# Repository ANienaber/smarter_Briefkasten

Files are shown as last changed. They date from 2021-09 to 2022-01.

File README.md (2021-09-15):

Der smarte Briefkasten, ermöglicht es Pakete von Personen zu empfangen, wenn man nicht anwesend ist. 
Wird von dem vorne liegenden RFID-Sensor ein autorisierter Tag erkannt, öffnen sich die Türen des Briefkasten. Legt man nun einen Gegenstand in den Briefkasten hinein, erkennt ein eingebauter Abstandssensor diesen und sendet durch die App Blynk eine Push Benachrichtung an das Handy des Nutzers. 
Geschlossen werden die Türen durch einen Knopfdruck.

Für den Zusammenbau werden MDF Holzbretterund Acrylglas, die mit einem Lasercutter geschnitten werden, ein 3D-Drucker. Hiermit werden die Modelle, die in dem Ordner Modellierung zu finden sind, gefertigt. Diese Modelle werden zusammengesteckt und geklebt
Zu dieser Hardware gehören, zwei ESP8266 D1 Mini Mikrocontroller, ein Taster, eine Tripler Base, ein Motorshield, zwei DC-Motoren, ein RFID-Sensor, und ein Abstandssensor.
Die beiden Dateien, die in dem Programmieren Ordner zu finden sind, müssen jeweils auf einen Mikrocontroller hochgeladen werden. 
Weitere Angaben zum Zusammenbau des Briefkasten können auf dem zugehörigen Blog gelesen werden. https://wp.uni-oldenburg.de/soft-skills-und-technische-kompetenz-wise20202021-sosepg-4/

Der Briefkasten wird wie folgt genutzt:
Bei erstmaliger Nutzung muss die Blynk App verbunden werden. Hierfür müssen im Programmcode die Wlan-Daten und der Authentifizierungstoken ergänzt werden. 
Außerdem sollte darauf geachtet werden, dass vor dem Start die Türen geschlossen sind. Ansonsten kann es sein, dass sich die Türen zu weit drehen. 
Die vorgesehene Bedienung des Briefkastens sieht wie folgt aus:

1. Den RFID Chip vor dem RFID Sensor halten, damit sich die Türen öffnen
2. Das Paket bzw. ein Gegenstand in den Briefkasten legen. Dann wird über die Blynk App eine Push Nachricht gesendet
3. Den Knopf betätigen, sodass sich die Türen wieder schließen
4. Mit dem RFID Chip die Türen wieder öffnen und das Paket entnehmen
5. Mit dem Knopf die Türen wieder schließen

Bekannte Probleme:
Türen lassen sich nicht mit dem RFID Chip öffnen:
Die Stromversorgung  muss neu eingeschaltet werden, bis die Türen wieder funktionieren. Bei erstmaliger Durchführung funktioniert es meist wieder.
Wenn der Briefkasten längere Zeit nicht genutzt wird, kann dieses Problem auftreten.

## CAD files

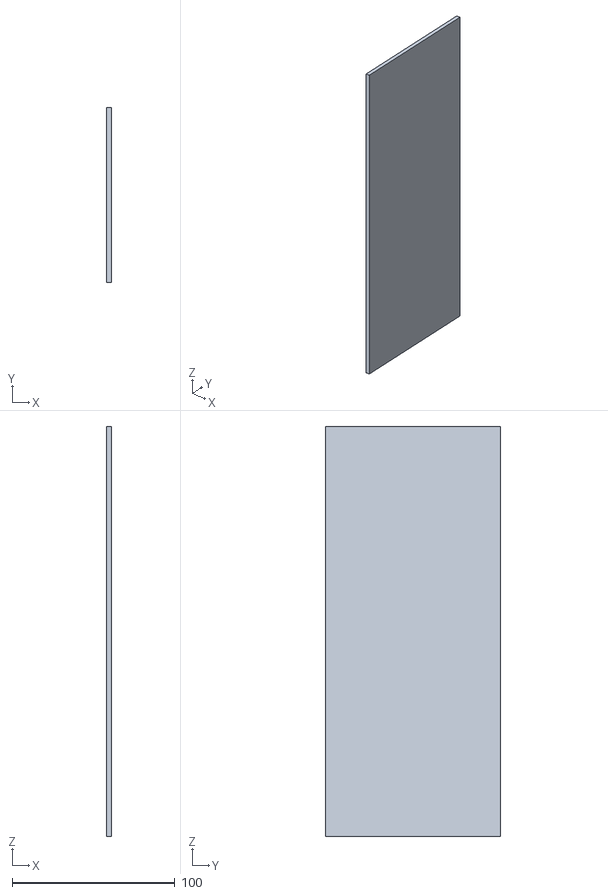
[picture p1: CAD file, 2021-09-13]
Modellierung/Tür.stl
3.00 x 107.5 x 252.0

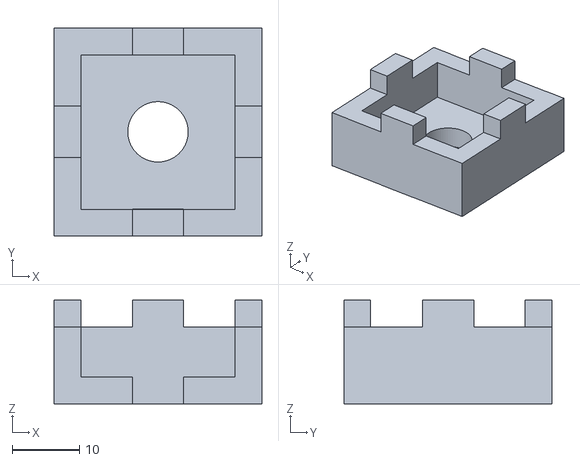
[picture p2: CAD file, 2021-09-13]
Modellierung/Kugellagerhalterung.stl
31.0 x 31.0 x 15.5

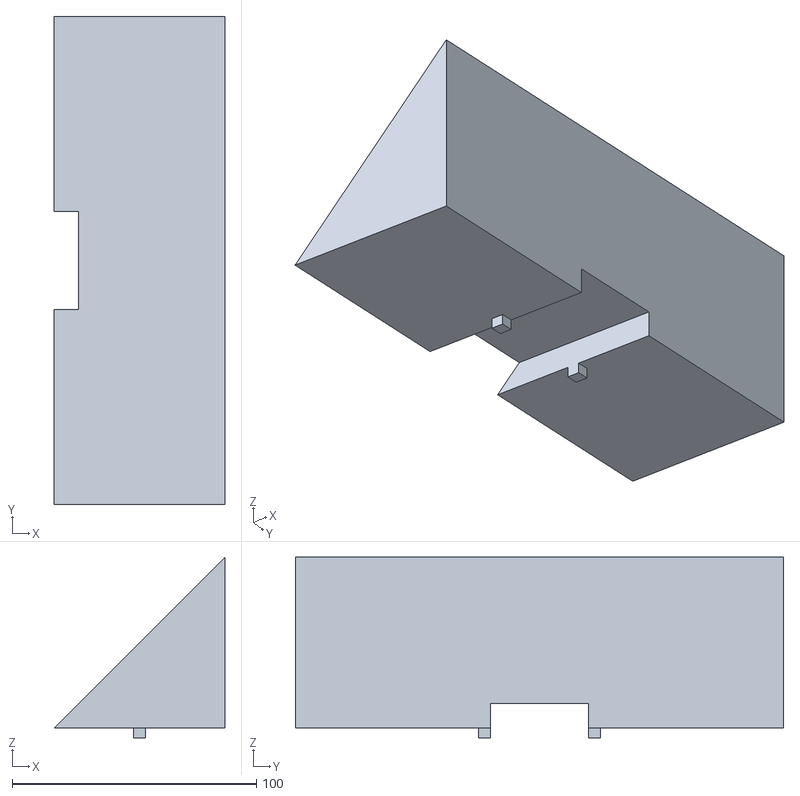
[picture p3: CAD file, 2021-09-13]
Modellierung/Schräge.stl
70.0 x 200.0 x 74.0

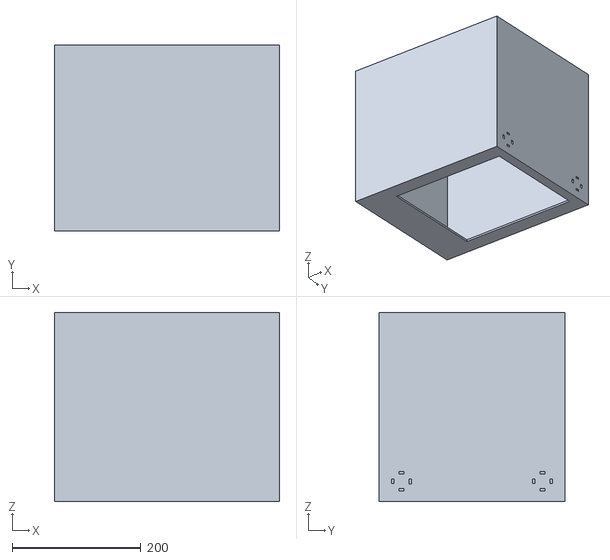
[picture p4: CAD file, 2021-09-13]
Modellierung/Oberkasten.stl
350.0 x 290.0 x 294.0

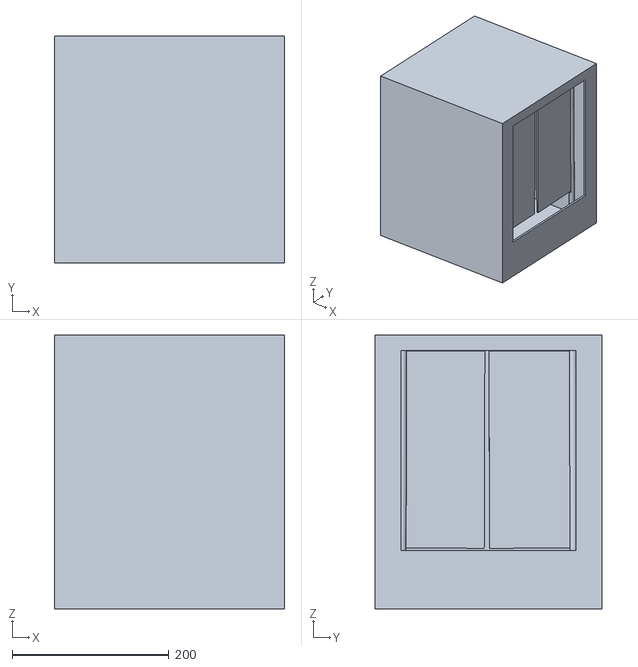
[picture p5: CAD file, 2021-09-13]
Modellierung/Gesamten_Oberkasten.stl
294.0 x 290.0 x 350.0

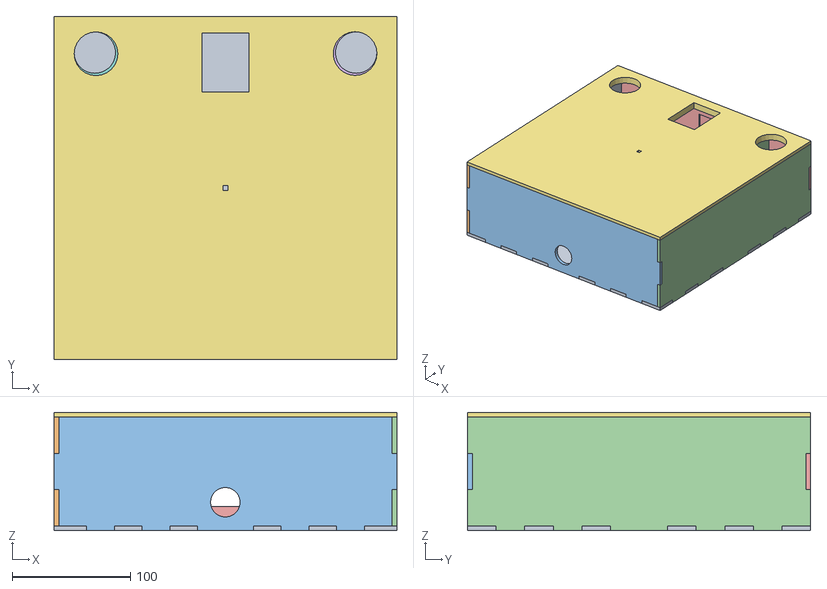
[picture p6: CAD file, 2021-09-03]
Modellierung/Unterbox.obj
290.0 x 290.1 x 100.0
Deckel

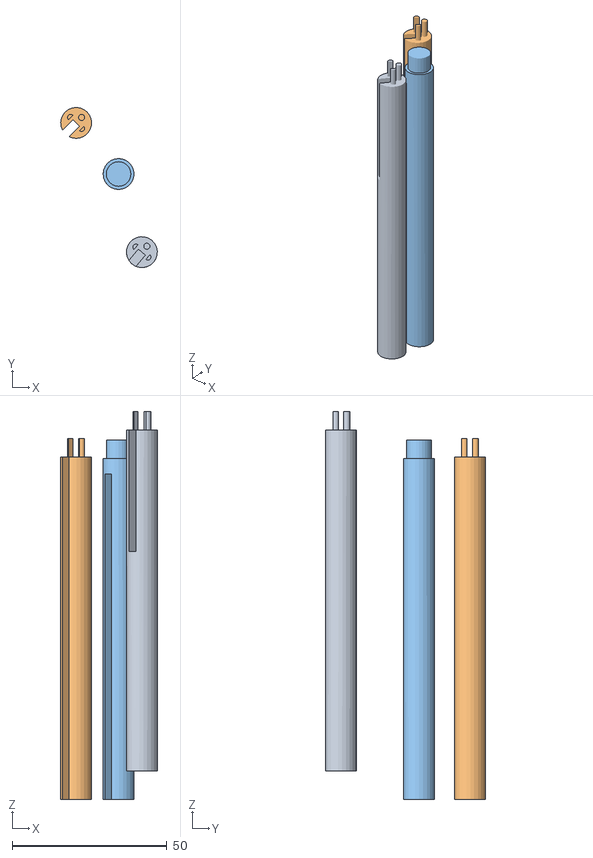
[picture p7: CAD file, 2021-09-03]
Modellierung/Saeule.obj
31.2 x 51.7 x 125.4
Säule unten
Säule mitte
Säule oben

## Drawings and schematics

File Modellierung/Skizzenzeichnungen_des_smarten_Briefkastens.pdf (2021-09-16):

9 | 10 | 11 | 12 | 13 | 14 | 15 | 16 | 17 | 18 | 19 | 20 | 21 | 22 | 23 | 24

290

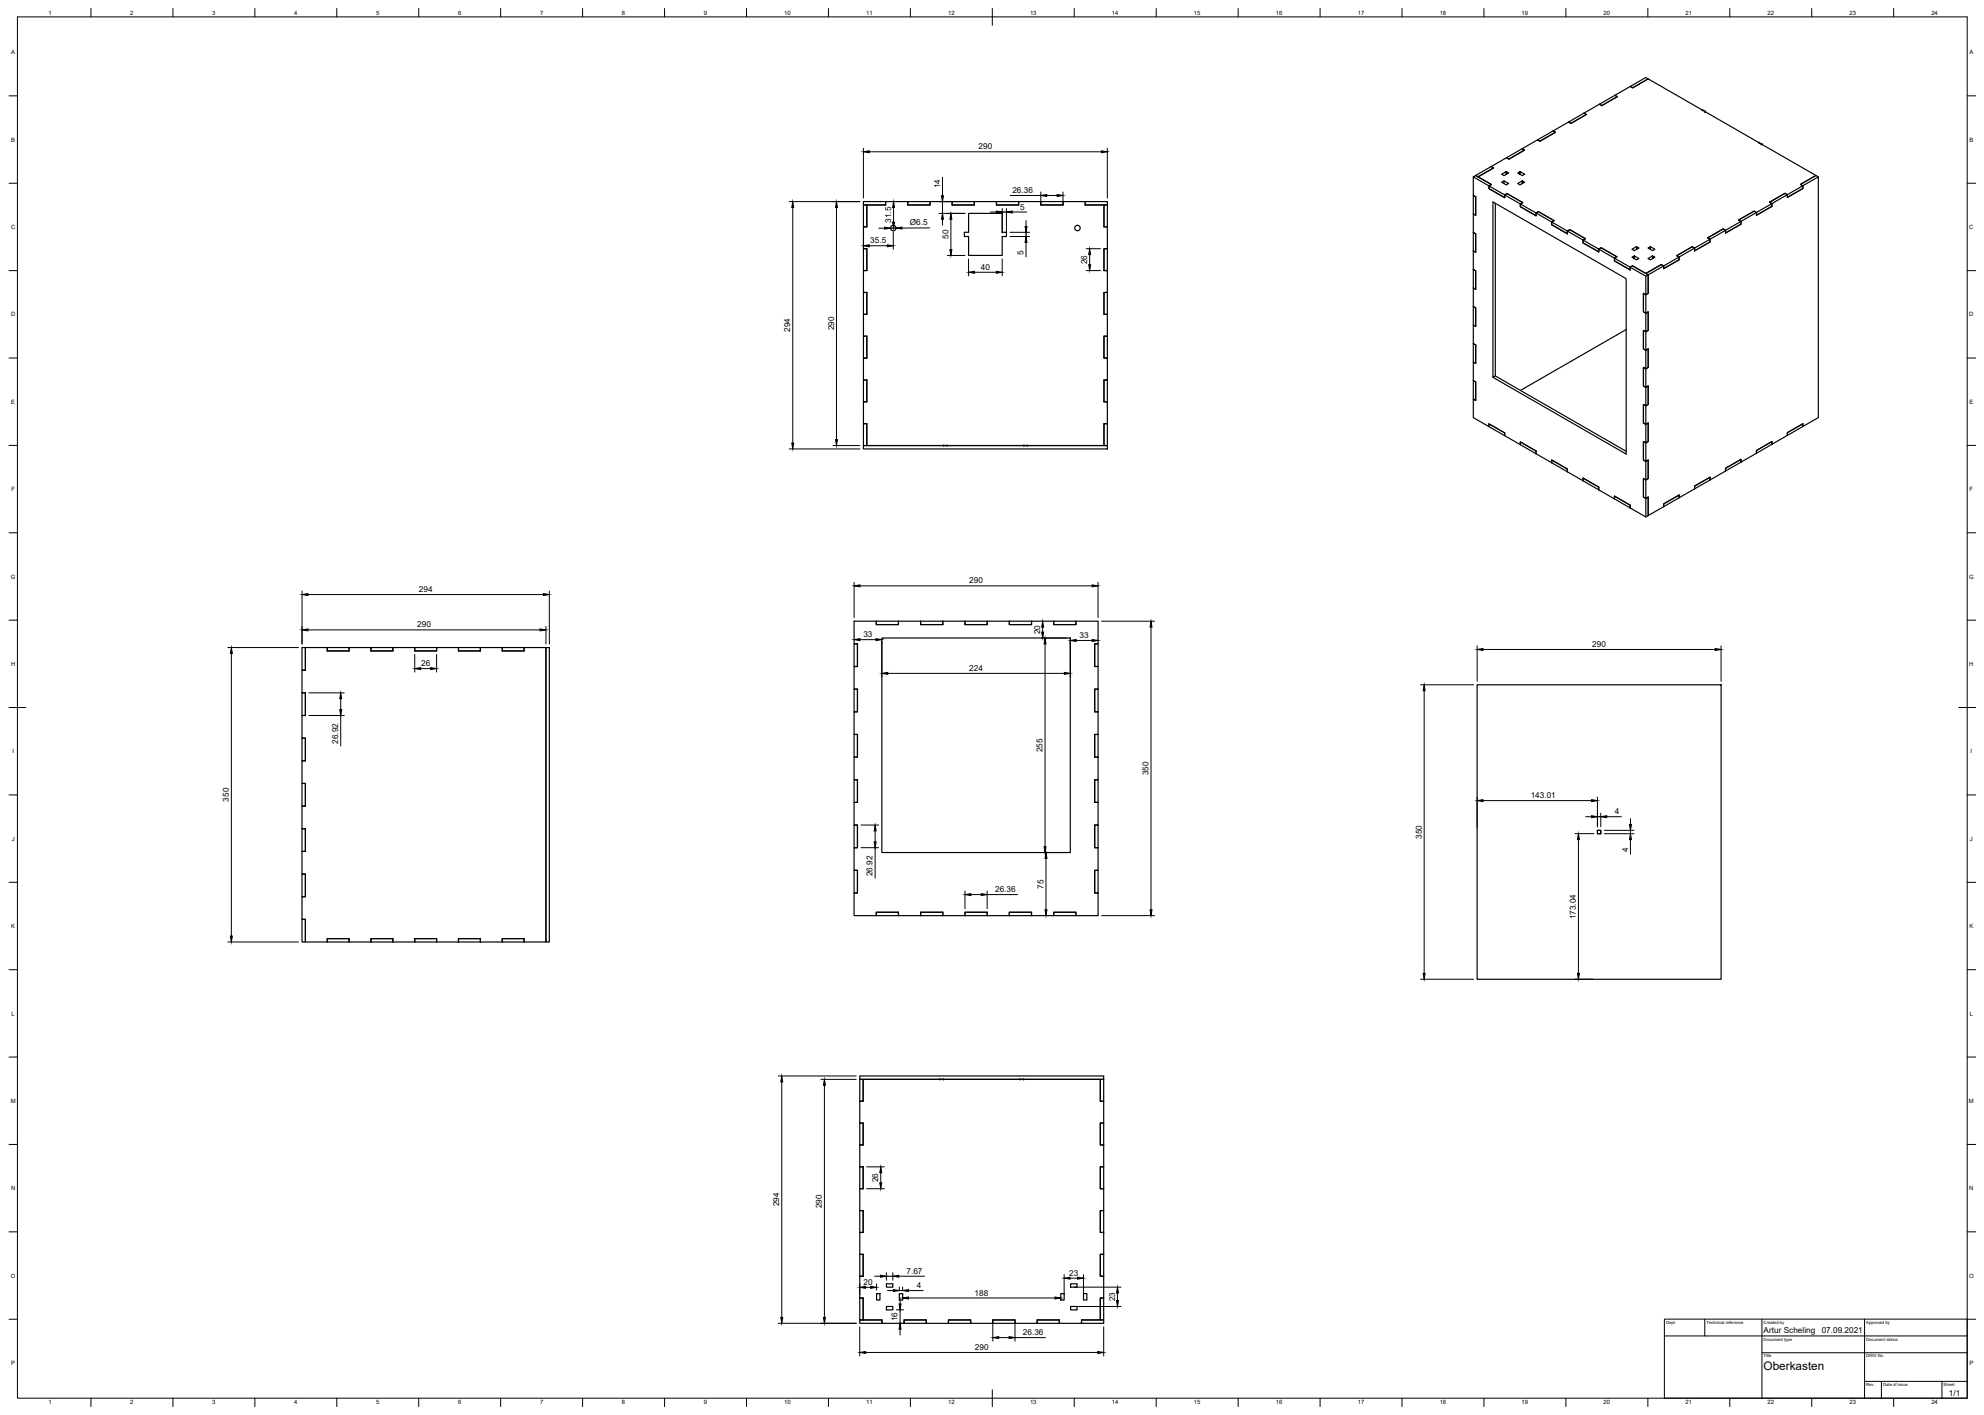
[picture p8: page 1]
BADCFEHGIKJMLONP; Dept.; Technical reference; Created by; Approved by; Artur Scheling

Document type | Document status

Title Oberkasten | DWG No.

Rev. | Date of issue | Sheet

1 | 2 | 3 | 4 | 5 | 6 | 7 | 8 | 9 | 10 | 11 | 12 | 13 | 14 | 15 | 16

B

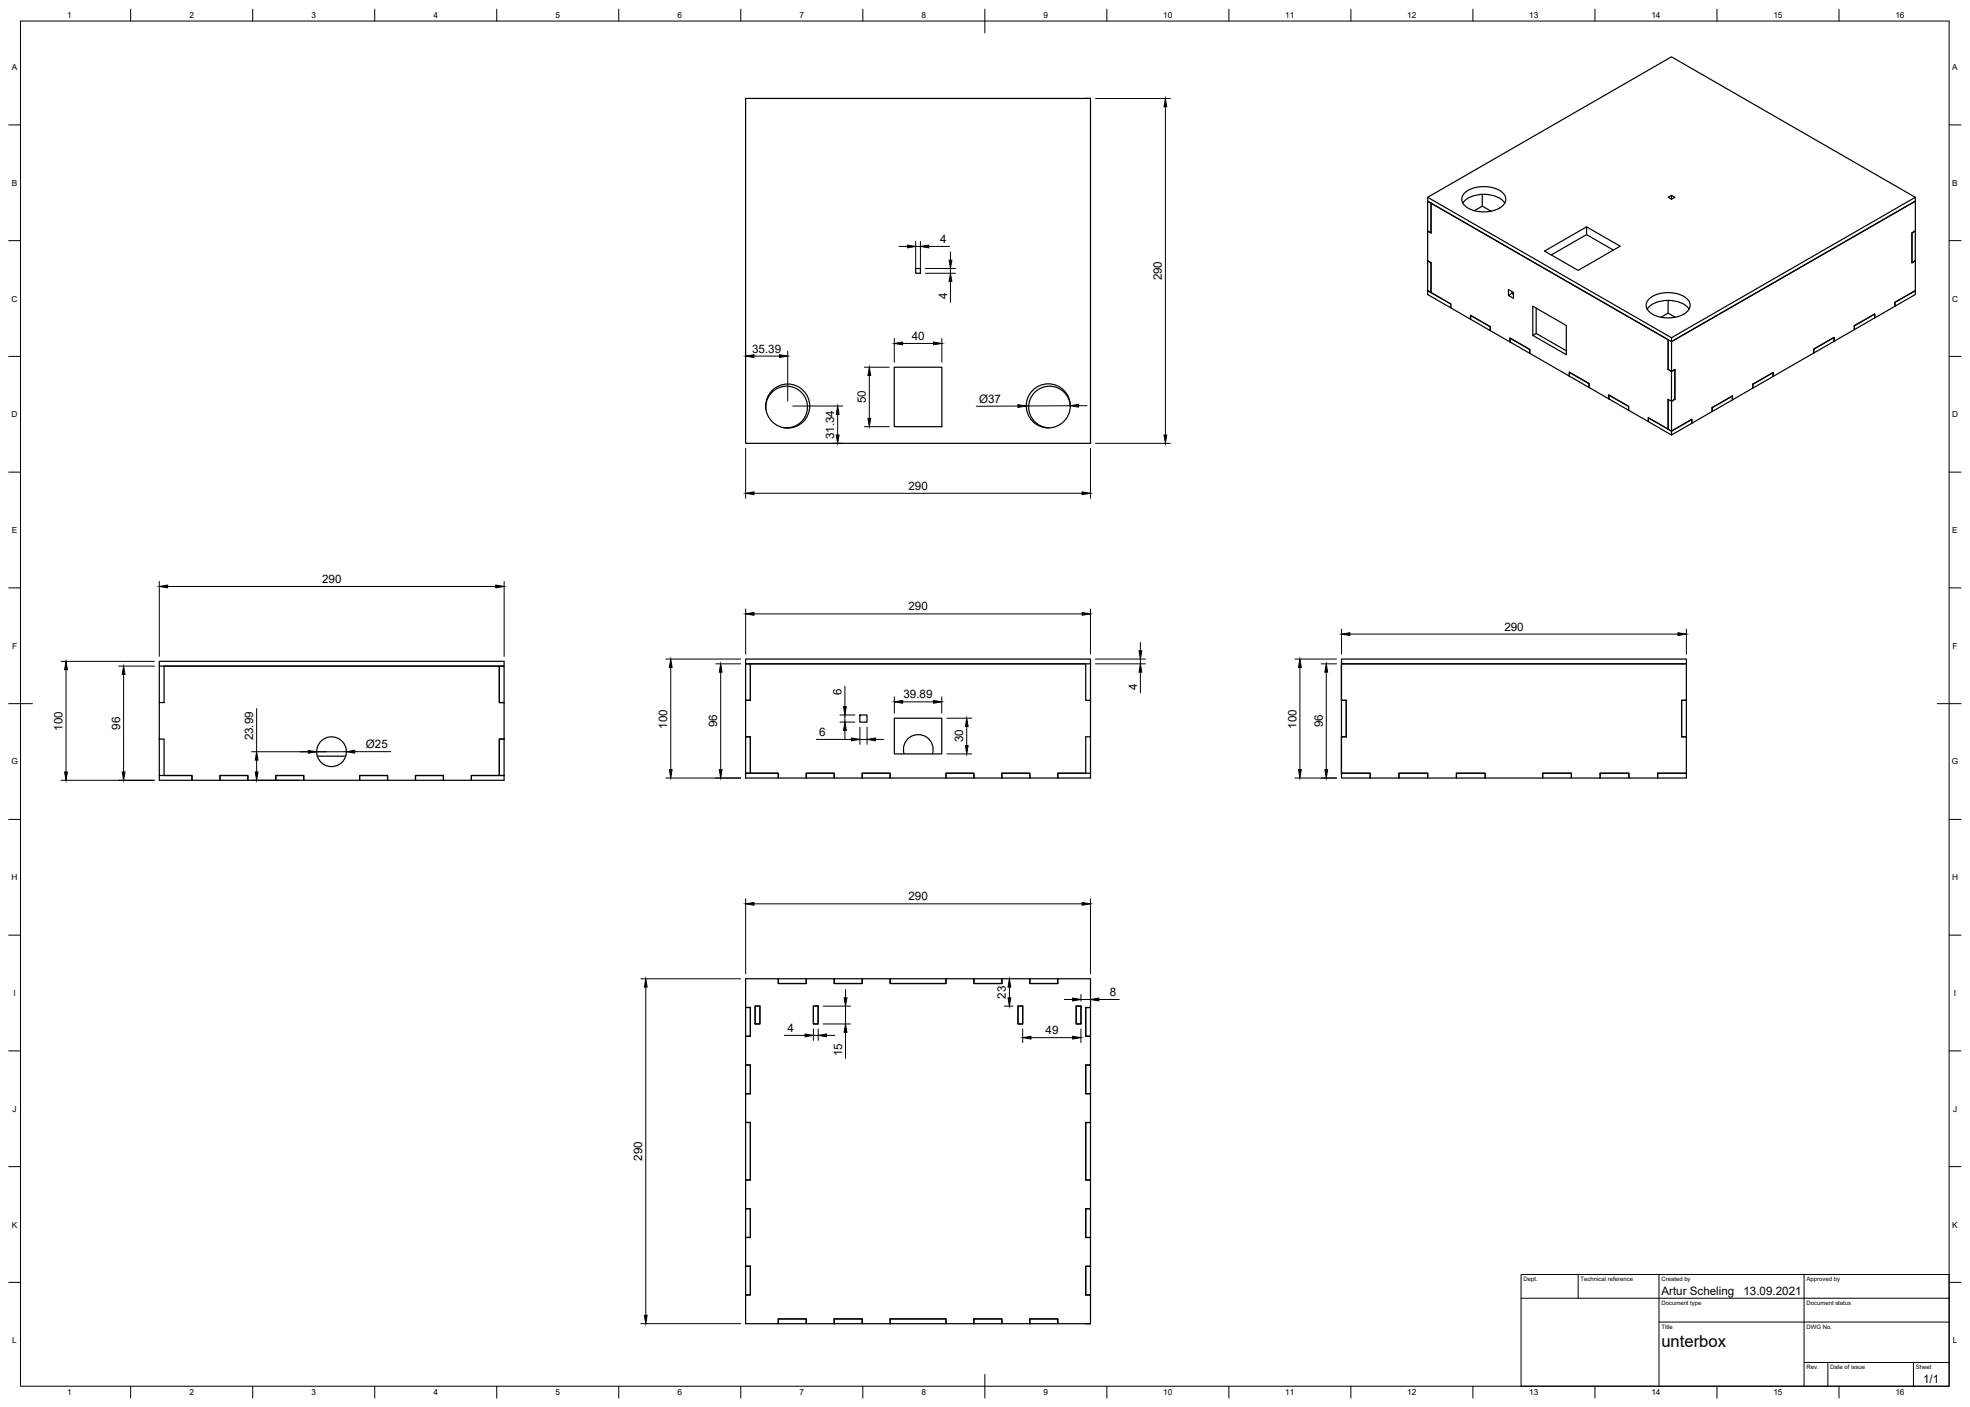
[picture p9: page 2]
Dept.; Technical reference; Created by; Approved by; Document type; Document status; unterbox; Artur Scheling

A

2 | 3 | 4 | 5 | 6 | 7 | 8

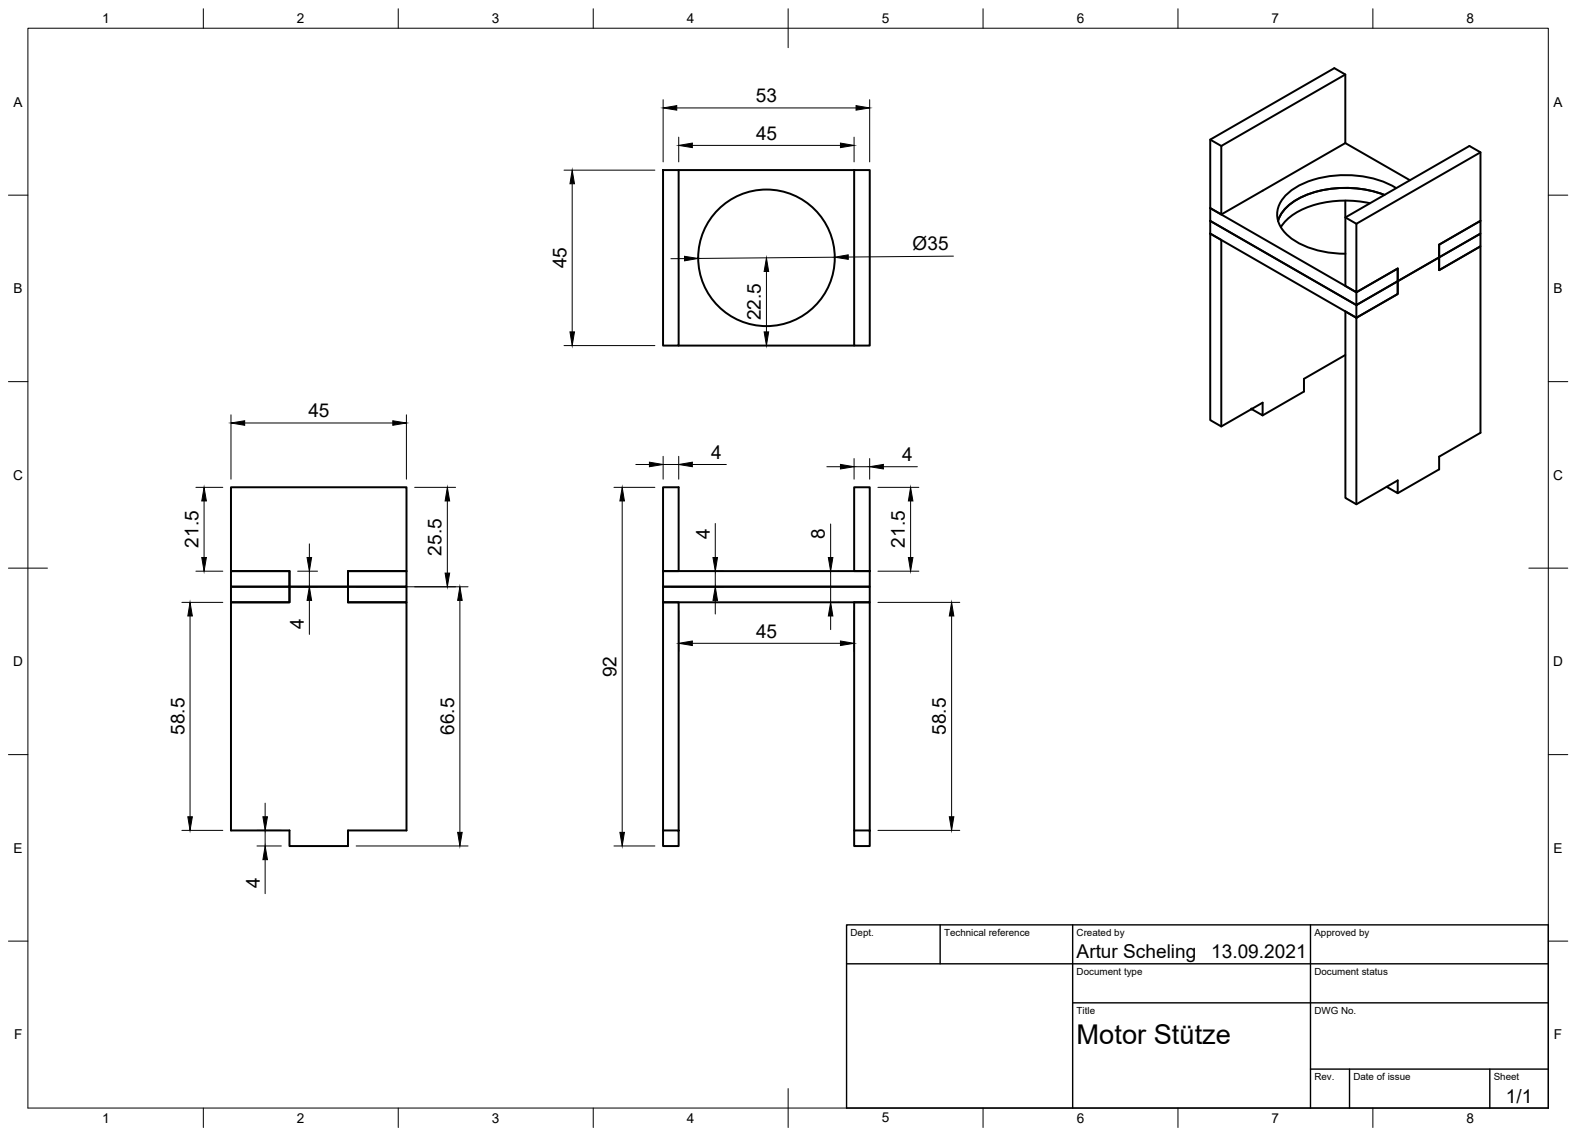
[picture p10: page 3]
Dept.; Technical reference; Created by; Approved by; Document type; Document status; Title; DWG No.; Motor Stütze; Artur Scheling

A

2 | 3 | 4 | 5 | 6 | 7 | 8

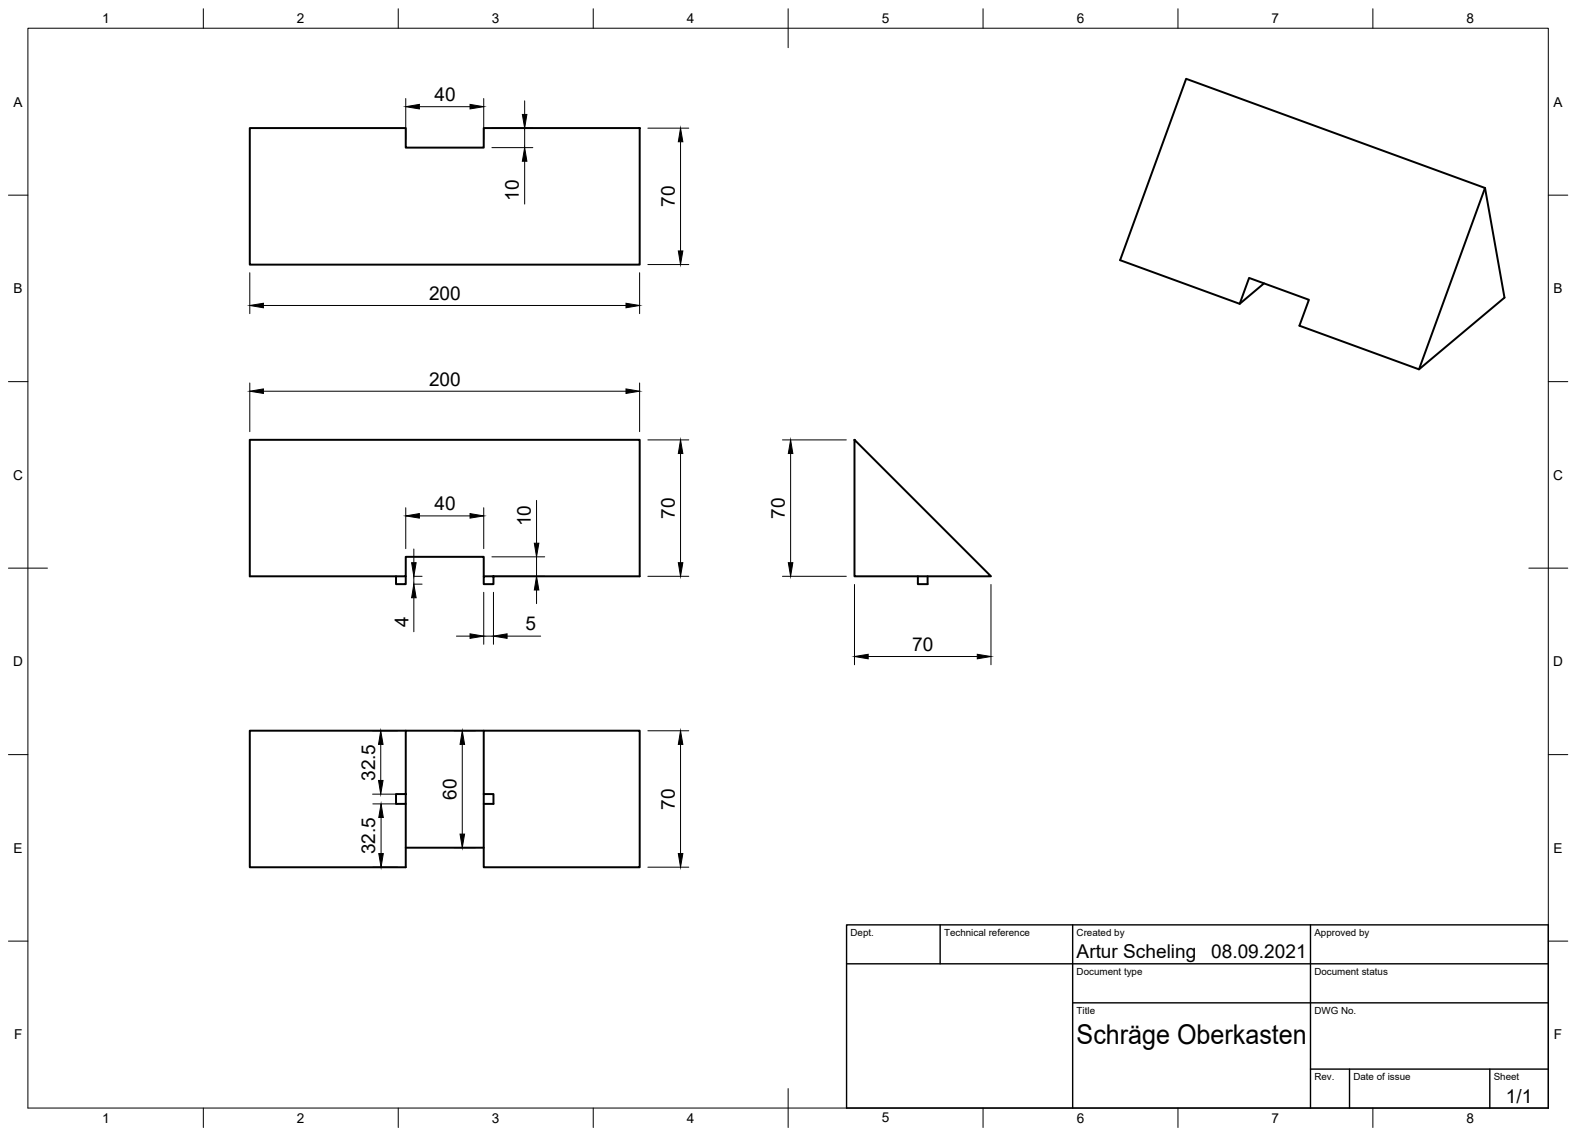
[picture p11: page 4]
Dept.; Technical reference; Created by; Approved by; Document type; Document status; Title; DWG No.; Schräge Oberkasten; Artur Scheling

1 | 2 | 3 | 4 | 5 | 6 | 7 | 8 | 9 | 10 | 11 | 12

B

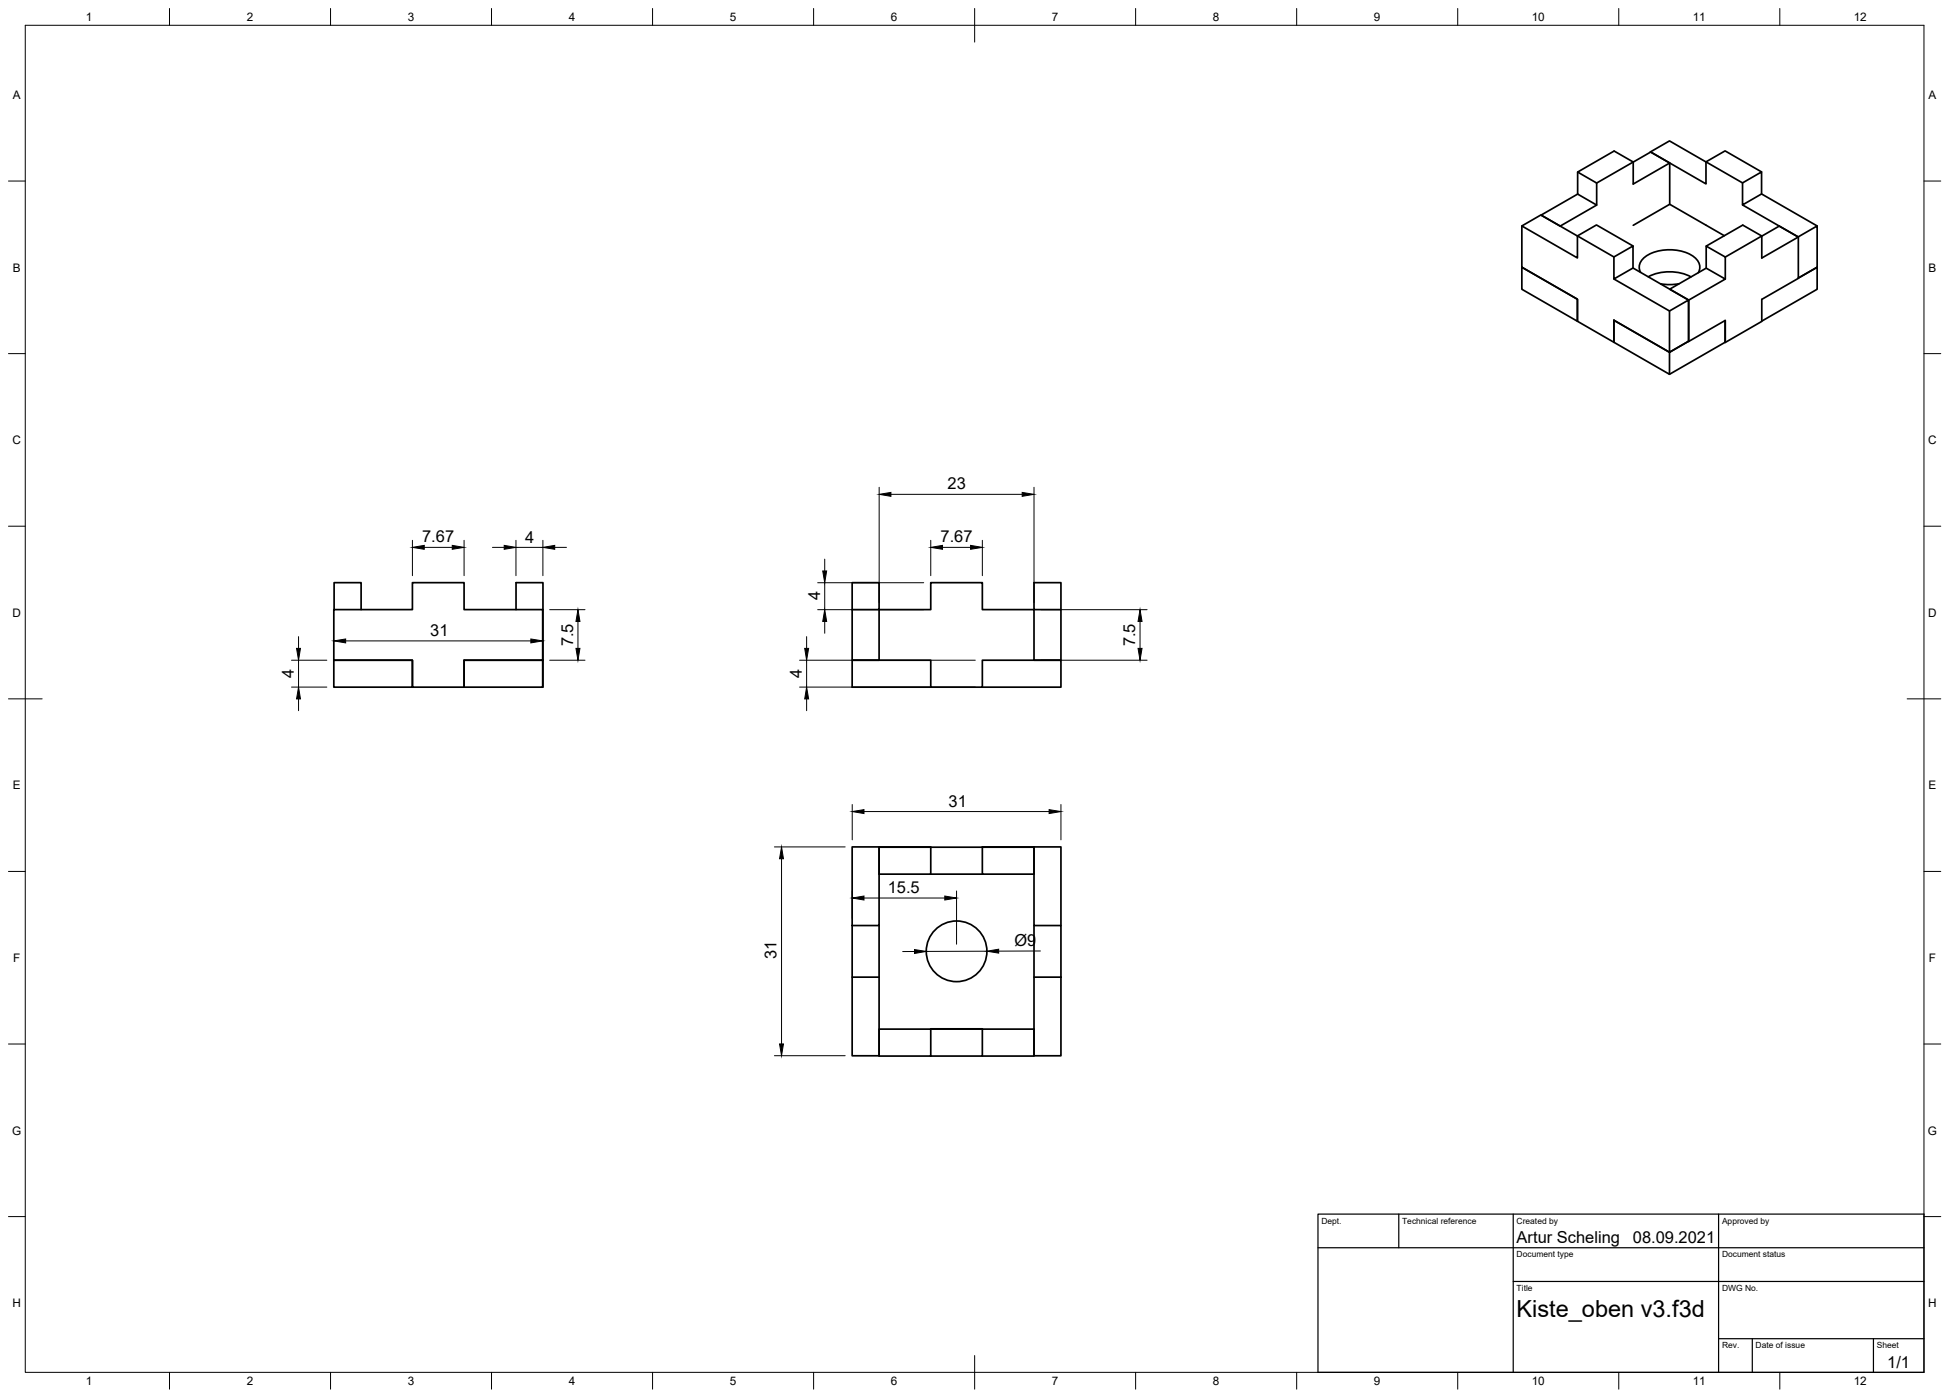
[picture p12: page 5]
Dept.; Technical reference; Created by; Approved by; Document type; Document status; Kiste_oben v3.f3d; Artur Scheling

Ø7.95

1.03

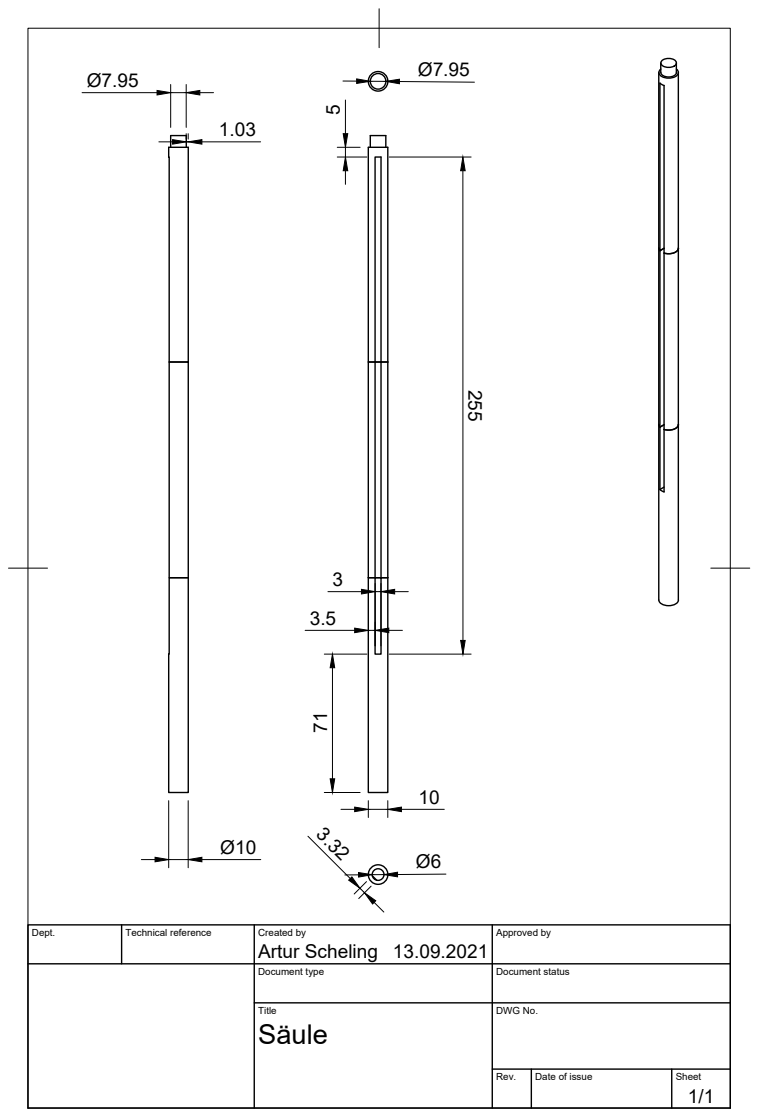
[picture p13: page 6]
Dept.; Technical reference; Created by; Approved by; Document type; Document status; Title; DWG No.; Säule; Artur Scheling

107.5
3

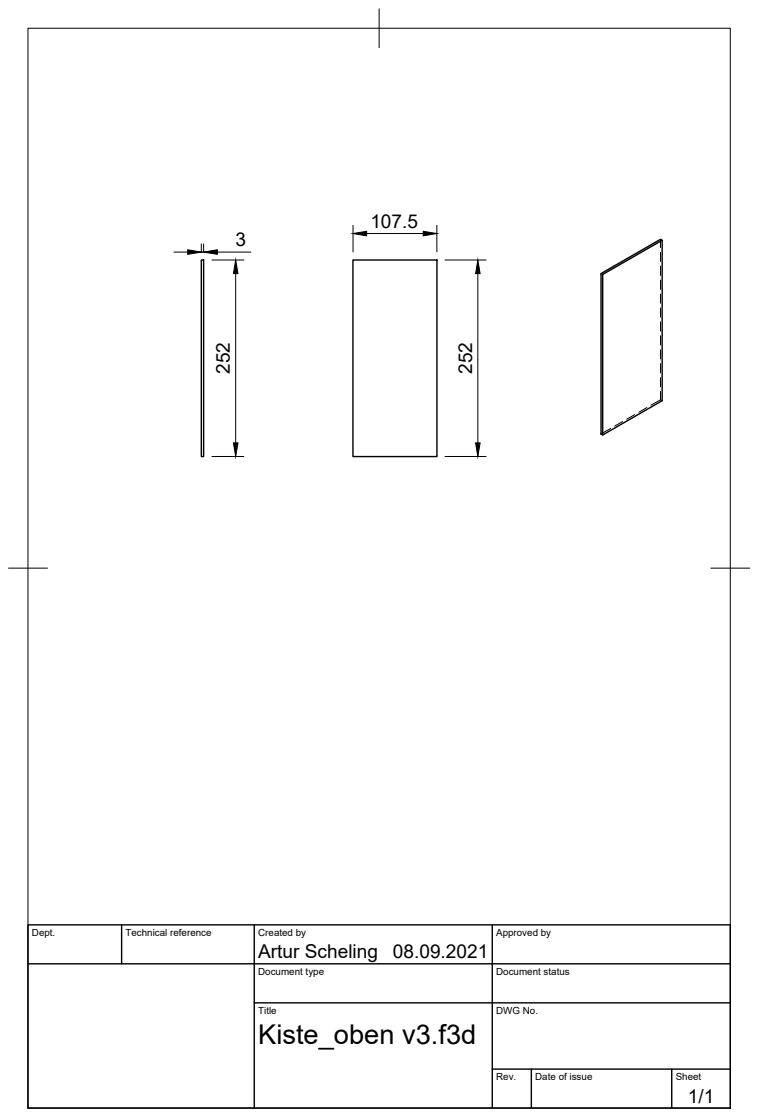
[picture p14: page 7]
Dept.; Technical reference; Created by; Approved by; Document type; Document status; Title; DWG No.; Kiste_oben v3.f3d; Artur Scheling

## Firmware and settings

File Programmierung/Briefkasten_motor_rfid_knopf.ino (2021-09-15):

//RFID Sensor Libraries
#include <SPI.h>
#include <MFRC522.h>
//Motor Library
#include <WEMOS_Motor.h>
//Motor shiled I2C Address: 0x30
//PWM frequency: 1000Hz(1kHz)
Motor M1(0x30,_MOTOR_A, 1000);//Motor A
Motor M2(0x30,_MOTOR_B, 1000);//Motor B

//Pins festelegen
//RFID
#define SS_PIN 15       //Pin D8
#define RST_PIN 0     //Pin D3

//Drehgeschwindigkeit der Motoren
const int SPEED = 50;
//Eingabe vom Taster
int taster;
//Hilfsvariable damit sich Türen nicht überdrehen
boolean isOpen = false;

//Variable um ID des RFID Chips speichern zu koennen
long chipID;
long grantedChipIDs[] = {913060, 1346750};
// MFRC522-Instanz erstellen
MFRC522 mfrc522(SS_PIN, RST_PIN);


  void setup(){ 
    //Build in LED zum Testend er Memory
    pinMode(LED_BUILTIN, OUTPUT);     // Initialize the LED_BUILTIN pin as an output
    
    // Taster Pin
    pinMode(D2, INPUT); 
    
    // SPI-Bus und MFRC522initialisieren
    SPI.begin();
    mfrc522.PCD_Init();
    delay(10);
    // Details vom MFRC522 RFID READER / WRITER ausgeben
    mfrc522.PCD_DumpVersionToSerial();
  }


  void loop(){
    //Serial.begin(115200);
    button();
    if(RFIDDetected()){
      openDoor();
      //Serial.println("loop nach open");
    }
    delay(100);
  }


  /* Nutzt RFID Sensor, um neu gelesenen Chip mit angegebener ChipID zu vergleichen.
   * Wenn der passende Chip gelesen wird, wird true zur�ckgegeben, sonst false.
   */
  boolean RFIDDetected(){
    if (mfrc522.PICC_IsNewCardPresent()){
       //ChipID wird resettet
       chipID = 0;
       mfrc522.PICC_ReadCardSerial();
       
       // Neue ChipID in Variable laden
       for (byte i = 0; i < mfrc522.uid.size; i++){
         chipID=((chipID+mfrc522.uid.uidByte[i])*10);
       }
       //Serial.println(chipID);

       //gelesene ChipID mit allen erlaubten ChipIDs vergleichen
       boolean grant = false;
       for(int i = 0; i < sizeof(grantedChipIDs); i++){
         long tempChipID = grantedChipIDs[i];
         if(chipID == tempChipID){
           grant = true;
         }
       }
       delay(250);
       //Je nach Ergebnis des Vergleichs wird true oder false zur�ckgegeben
       if (grant){
         //Serial.println("Zugang gewaehrt!");
         return true;
       } else {
         //Serial.println("Chip hat keine Zugangsrechte!");
         return false;
       }
    } else {
      //Serial.println("keinen Chip erkannt");
      return false;
    }
  }

  //oefnnet die Tueren des Briefkasten
  void openDoor(){  
    //Abfrage damit Türen sich nicht überdrehen
    if(isOpen){
      //Serial.println("Tür ist bereits geoeffnet!");
      return;
    }
    delay(200);
    //Motoren drehen sich im Uhrzeigersinn mit Geschwindikeit SPEED
    M1.setmotor( _CW, SPEED);
    M2.setmotor(_CCW, SPEED);
    //Motoren drehen sich für 1500 ms
    delay(1500);
    //Motoren werden angehalten
    M1.setmotor(_STOP);
    M2.setmotor(_STOP);
    //Zustand der Tür zwischenspeichern
    isOpen = true;
  }

  //Schliesst die Tueren des Briefkastens
  void closeDoor(){
     if(!isOpen){
      //Serial.println("Tür ist bereits geschlossen!");
      return;
     }
     delay(200); 
     M1.setmotor( _CCW, SPEED);
     M2.setmotor(_CW, SPEED);
     delay(1500);
     M1.setmotor(_STOP);
     M2.setmotor(_STOP);
     isOpen = false;
  }


  void button(){
    taster = digitalRead(D0);
    //Serial.println(digitalRead(D0));
    delay(250);
    if(taster == HIGH){
    closeDoor();
    }
}

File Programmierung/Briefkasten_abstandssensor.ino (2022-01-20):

/////Blynk Libraries
#include <ESP8266WiFi.h>
#include <BlynkSimpleEsp8266.h>
#define BLYNK_PRINT Serial
//Variablen zur Verbindung mit Blynk
char auth[] = "j_VuyJY24SRmAzo7RVOjfWb3cR2vgpGk";
char ssid[] = "";
char pass[] = "";

//Standardwert vom Abstandssensor, wenn kein Paket im Briefkasten ist
const int MAX_DISTANCE = 1000;

//Hilfsvariable damit Pushnachricht nur einmal geschickt wird
boolean package = false;

void setup() {
    Serial.begin(115200);
    //mit Blynk verbinden
    Blynk.begin(auth, ssid, pass);
    delay(500);
    //LichtschrankenPin als Ouput definieren
    pinMode(A0, INPUT);
}

void loop() {
  //whilfe-Schleife zur Sicherstellung der Verbinfung und erneuter Verbindung bei Abbruch
  while(Blynk.connected() == false){
    Blynk.connect();
    Serial.print(".");
  }
  Blynk.run();
  if(packageDetected()){
    delay(2000);
    Blynk.notify("Du hast ein Paket erhalten!");
    Serial.println("Paket");
  }
}

  /* Nutzt Abstandsensor, um Paket zu erkennen.
   * Sendet eine Nachricht via Blynk, falls ein neues Paket geliefert wurde.
   */
  boolean packageDetected(){
    //Wert den der Abstandssensor ausgibt
    int distance = analogRead(A0);
    //Delay, da auslesen des A0 Pins sonst WLAN Verbindung stört
    delay(100);
    //Wenn ein Paket vorliegt und Nachricht noch nicht gesendet wurde
    if(distance <= MAX_DISTANCE && package == false){
      package = true;
      return true;
    }
    //Wenn Paket entnommen wurde, dann setze alles auf Anfang, um neues Paket erkennen zu können
    if(distance > MAX_DISTANCE){
      package = false;
      return false;
    }

    return false;

}

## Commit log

2021-09-03 Motorsteuerung wurde hinzugefügt
2021-09-03 Add files via upload
    Die Modelle für die Säule und den Unterkasten wurden finalisiert.
    [Saeule.obj, unterbox.obj]
2021-09-06 EEPROM implementiert
    Speicherung des Zustands bei Stromverlust
2021-09-12 packageDetected fix, Button fix
2021-09-13 Abstandssensor und Blynk ausgelagert
    Blynk Benachrichtigungen nach Erkennen eines Pakets werden nun durch einen zweiten Mikrocontroller übernommen.
2021-09-13 Code auf zwei Controller aufgeteilt
    Siehe Briefkasten_abstandssensor.ino und Briefkasten_motor_rfid_knopf.ino
2021-09-13 3D-Modell des gesamten Oberkastens
    Diese Datei ist ein Fusion 360 Projekt, des gesamten Oberkastens. Dort sind der Oberkasten, die Kugellagerhalterungen, die Schräge, die Türen und die Säulen abgebildet.
2021-09-13 3D-Modell des gesamten Oberkastens
    Diese Datei bildet den gesamten Oberkasten des smarten Briefkastens ab. Diese Datei enthält den Oberkasten, die Kugellagerhalterungen, die Schräge, die Säulen und die Türen.
    [Gesamten_Oberkasten.stl]
2021-09-13 3D-Modell des Oberkasten
    Bei dieser Datei handelt es sich um das 3D-Modell des Oberkastens des smarten Briefkastens.
    [Oberkasten.stl]
2021-09-13 3D-Modell der Schräge
    Bei dieser Datei handelt es sich um das 3D-Modell der Schräge des smarten Briefkastens.
    [Schräge.stl]
2021-09-13 3D-Modell der Kugellagerhalterung
    Bei dieser Datei handelt es sich um das 3D-Modell der Kugellagerhalterung des smarten Briefkastens.
    [Kugellagerhalterung.stl]
2021-09-13 3D-Modell der Tür
    Bei dieser Datei handelt es sich um das 3D-Modell der Tür des smarten Briefkastens.
    [Tür.stl]
2021-09-13 Skizzenzeichnung des smarten Briefkastens
    In dieser PDF-Datei befinden sich Skizzenzeichnungen vom Oberkasten, vom Unterkasten, von den Motor Stützen, von der Schräge, von den Kugellagerhalterungen, von den Säule und von den Türen.
2021-09-13 Datei in Ordner verschoben
    [Saeule.obj]
2021-09-13 Dateien verschoben und umbenannt
    [Kugellagerhalterung.stl, Oberkasten.stl, Schräge.stl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]
2021-09-13 Datei verschoben und umbenannt
    [Gesamten_Oberkasten.stl]
2021-09-15 Übersichtlichkeit gesteigert
    Kommentare wurden erneut hinzugefügt und übersichtlicher gestaltet
2021-09-16 Skizzenzeichnungen des smarten Briefkastens
    Diese PDF-Datei enthält folgende Skizzenzeichnungen der Komponenten des smarten Briefkastens:
    - Oberkasten
    - Unterkasten
    - Motor Stütze
    - Schräge
    - Kugellagerhalterung
    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
